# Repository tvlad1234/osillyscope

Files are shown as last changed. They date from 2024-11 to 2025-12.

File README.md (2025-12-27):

# osillyscope
CH32V003 OLED screen oscilloscope

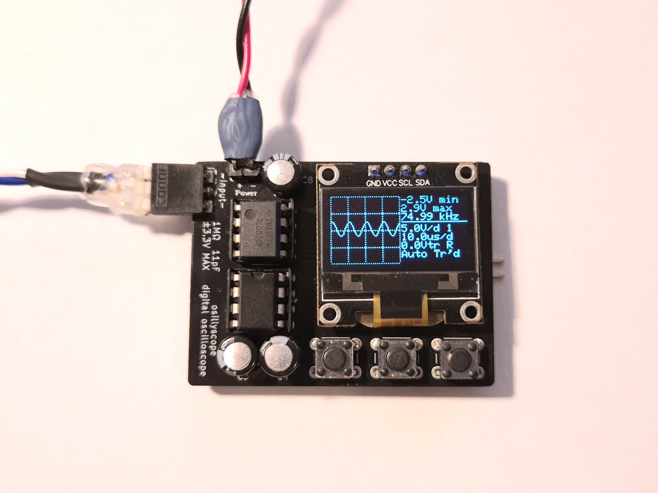
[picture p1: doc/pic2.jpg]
The osillyscope


 **Many thanks to [PCBway](https://www.pcbway.com/) for sponsoring this project with fast high-quality PCB prototyping.**

This is a small digital oscilloscope based around the CH32V003A4M6 RISC-V microcontroller. It uses an SSD1306 I2C OLED display and three pushbuttons for the user interface. Its purpose is to be an inexpensive, easy to build and pocket-sized tool for checking the presence, levels and waveform of an unknown signal. The hardware design focuses on simplicity and low-count bill of materials.

The maximum achievable sample rate is 1.6MSa/s (the time base goes as low as 5us/div). This project proposes a frontend design which allows for a signal input range between -3.3V and +3.3V. The input range can be extended using a standard 10x probe, as the instrument has 1MOhm of input impedance. The bandwidth of the frontend was measured to be around 2.5MHz. 

## Hardware
The schematics and board design files (KiCad 7) are provided in the [hw](hw) folder. Two PCB designs are included: [a 2-layer design, meant to be sent to a PCB fab](hw/osillyscope-2layer/) and [a single layer one, designed to be easily etchable](hw/osillyscope-etchable/).

### **PCBs**
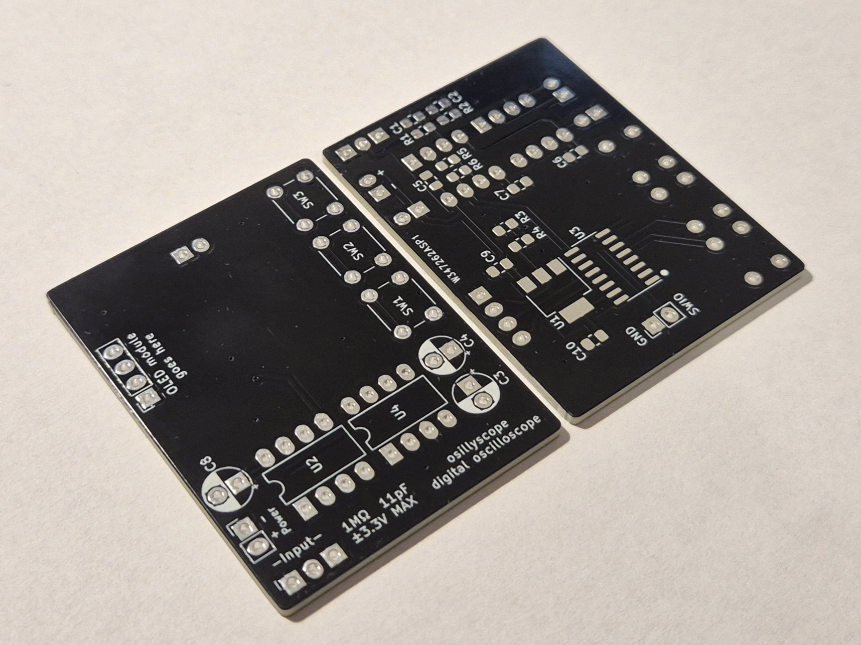
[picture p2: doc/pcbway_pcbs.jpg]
PCBs from PCBway


Very shortly after I had published this project, PCBWay reached out to me, offering to try their PCB prototyping services. About a week after placing the order, the boards had arrived, and here are my thoughts on the service they provided:

I'm very pleased with them. They feel dense and solid, I had absolutely no trouble soldering them up. With such a relatively simple, untested board design, I chose to go with HASL finish. While assembling, I had to desolder and resolder the power pin header, and the pads didn't show any signs of possible failure or fatigue (I had that happen often with various circuit boards in the past, but I had no issues with these ones). Visually, I opted for black solder mask. It looks absolutely beautiful, glossy and uniformly coated, honestly the picture above doesn't show it in all of its beauty. The silkscreen is crisp, precise and nicely aligned.

Ordering from them was quite a breeze using their KiCad plugin, which automatically plots and uploads the Gerber files into their ordering platform with a single click. I find their service affordable, I ordered 10 boards (2 layers, 1.6mm with HASL finish) and the price for the boards came to be 5USD.

This was my first experience with PCBWay's prototyping service, and it's been a pleasant one. I will certainly consider them again for my next PCB prototyping needs, and I warmly encourage you too will give them a try.

### Circuitry  
The analog frontend consists of a 2x attenuator, opamp buffer stage and DC offset stage. An ICL7660 voltage converter IC provides the negative supply voltage for the TL082 dual opamp. The oscilloscope can be powered from a 5 or more volts supply, such as a 9V battery.

The schematics are also provided as PDF, in [doc/schematic.pdf](doc/schematic.pdf).

## Code
The firmware source code is provided in the [fw](fw) folder. It uses the [ch32fun](https://github.com/cnlohr/ch32fun/) framework.

The ADC operates in continuous conversion mode and samples are fetched into a circular buffer via DMA. Triggering is achieved using the analog watchdog feature of the ADC.

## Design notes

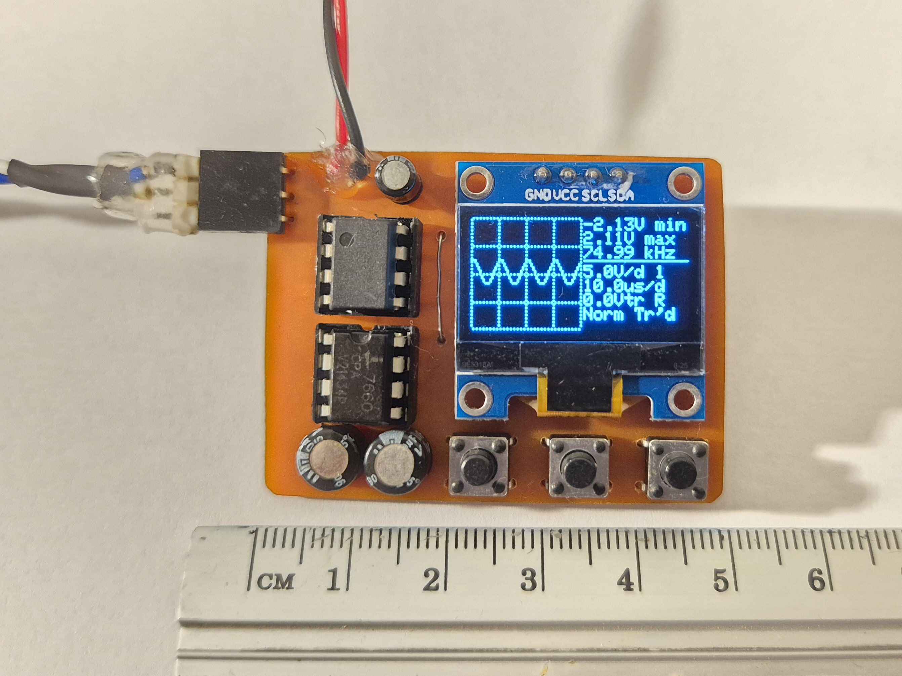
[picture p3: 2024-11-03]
doc/pic.jpg

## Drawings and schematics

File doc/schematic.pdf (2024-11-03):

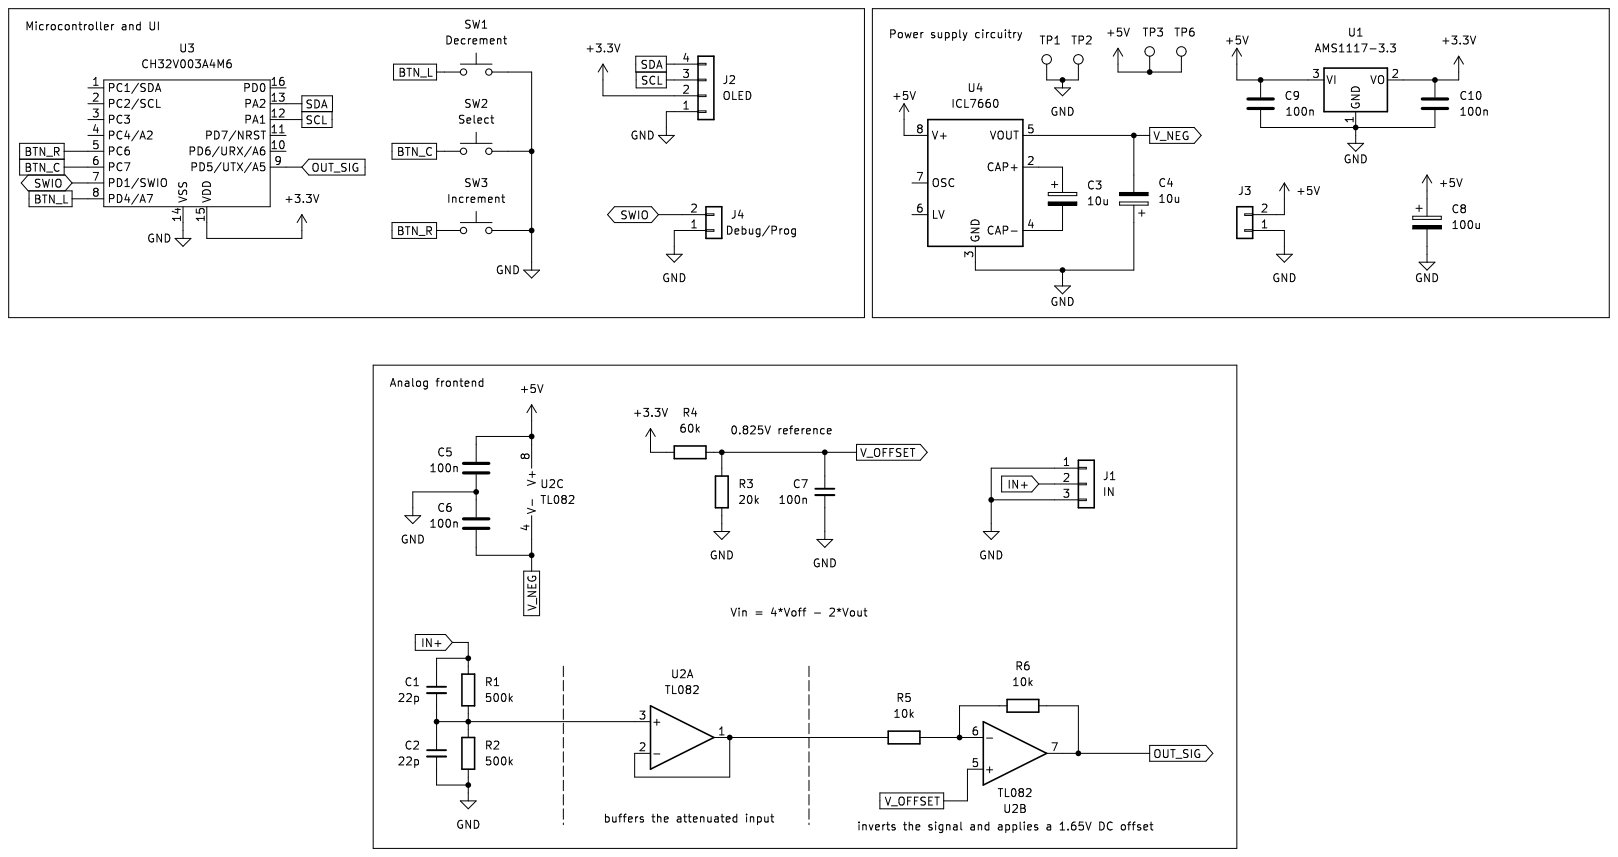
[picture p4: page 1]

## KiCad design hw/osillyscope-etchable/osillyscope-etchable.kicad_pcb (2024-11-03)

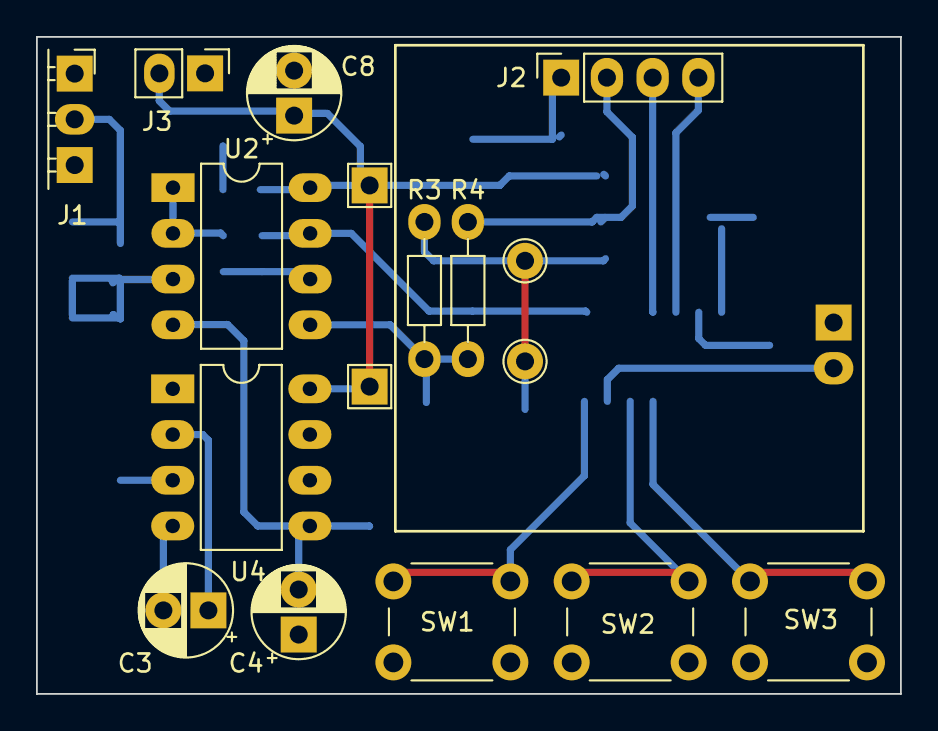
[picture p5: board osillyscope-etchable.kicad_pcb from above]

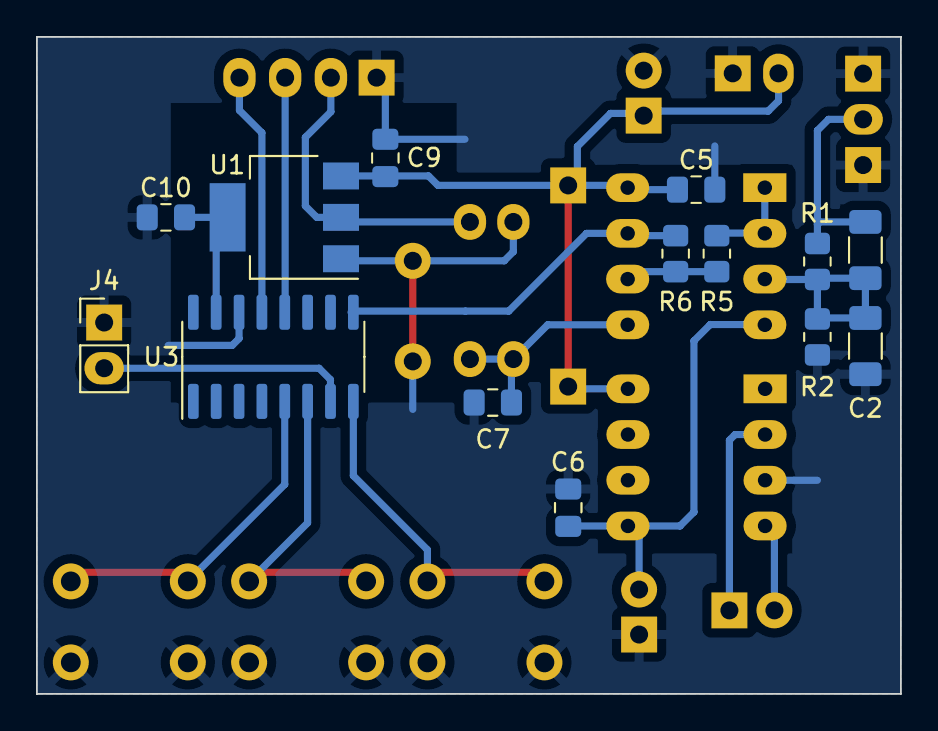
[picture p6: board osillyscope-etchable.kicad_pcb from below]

Board: 2 copper layers, 48.0 x 36.5 mm, 31 parts (14 on the bottom side), 18 nets.

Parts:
C1, C2: 22p; C_1206_3216Metric_Pad1.33x1.80mm_HandSolder
C3, C4: 10u; CP_Radial_D5.0mm_P2.50mm
C5, C6, C7, C9, C10: 100n; C_0805_2012Metric_Pad1.18x1.45mm_HandSolder
C8: 100u; CP_Radial_D5.0mm_P2.50mm
J1: IN; PinSocket_1x03_P2.54mm_Horizontal
J2: OLED; PinSocket_1x04_P2.54mm_Vertical
J3: Conn_01x02; PinHeader_1x02_P2.54mm_Vertical
J4: Debug/Prog; PinHeader_1x02_P2.54mm_Vertical
R1, R2: 500k; R_0805_2012Metric_Pad1.20x1.40mm_HandSolder
R3: 20k; R_Axial_DIN0204_L3.6mm_D1.6mm_P7.62mm_Horizontal
R4: 60k; R_Axial_DIN0204_L3.6mm_D1.6mm_P7.62mm_Horizontal
R5, R6: 20k; R_0805_2012Metric_Pad1.20x1.40mm_HandSolder
SW1: Decrement; SW_PUSH_6mm
SW2: Select; SW_PUSH_6mm
SW3: Increment; SW_PUSH_6mm
TP1, TP2: TestPoint; TestPoint_THTPad_D2.0mm_Drill1.0mm
TP3, TP6: TestPoint; TestPoint_THTPad_2.0x2.0mm_Drill1.0mm
U1: AMS1117-3.3; SOT-223-3_TabPin2
U2: TL082; DIP-8_W7.62mm_LongPads
U3: CH32V003A4M6; SOIC-16_3.9x9.9mm_P1.27mm
U4: ICL7660; DIP-8_W7.62mm_LongPads

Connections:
+3.3V: C10.1, J2.2, R4.1, U1.2 (VO), U3.15 (VDD)
+5V: C5.1, C8.1, C9.2, J3.2, TP3.1, TP6.1, U1.3 (VI), U2.8 (V+), U4.8 (V+)
BTN_C: SW2.1, U3.6 (PC7)
BTN_L: SW1.1, U3.8 (PD4/A7)
BTN_R: SW3.1, U3.5 (PC6)
GND: C2.2, C4.1, C5.2, C6.1, C7.2, C8.2, C9.1, C10.2, J1.1, J1.3, J2.1, J3.1, J4.1, R2.2, R3.2, SW1.2, SW2.2, SW3.2, TP1.1, TP2.1, U1.1 (GND), U3.14 (VSS), U4.3 (GND)
IN+: C1.1, J1.2, R1.1
unnamed: C1.2, C2.1, R1.2, R2.1, U2.3 (+)
unnamed: R5.1, U2.1, U2.2 (-)
unnamed: R5.2, R6.2, U2.6 (-)
unnamed: C3.1, U4.2 (CAP+)
unnamed: C3.2, U4.4 (CAP-)
OUT_SIG: R6.1, U2.7, U3.9 (PD5/UTX/A5)
SCL: J2.3, U3.12 (PA1)
SDA: J2.4, U3.13 (PA2)
SWIO: J4.2, U3.7 (PD1/SWIO)
V_NEG: C4.2, C6.2, U2.4 (V-), U4.5 (VOUT)
V_OFFSET: C7.1, R3.1, R4.2, U2.5 (+)

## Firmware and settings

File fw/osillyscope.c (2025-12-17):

/*
 * CH32V003 oscilloscope
 * by tvlad1234
 */

#include "ch32fun.h"

#include "scope.h"
#include "ui.h"

// ADC capture buffers
volatile uint16_t wave_buf[DISP_BUF_LEN] = {0};
volatile uint16_t adc_buf[CIRC_BUF_LEN] = {0}; // circular

oscilloscope_t oscope = {
	.wave_buf = wave_buf,
	.adc_buf = adc_buf,

	.dma_ready = 1,

	.trig_level = 502,
	.trig_state = NO_TRIGGER,

	.tdiv_sel = 1,
	.vdiv_sel = 2,

	.runmode = RUN_AUTO,
};

int main()
{
	SystemInit();
	RCC->APB2PCENR |= RCC_APB2Periph_GPIOD | RCC_APB2Periph_GPIOC | RCC_APB2Periph_GPIOA;

	// Let power supplies settle before initializing ADC and OLED
	Delay_Ms(250);

	init_oscilloscope(&oscope);

	while (1)
	{
		// Waveform capture
		capture_waveform(&oscope);

		// User interface
		scope_ui(&oscope);
	}
}

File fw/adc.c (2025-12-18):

#include "ch32fun.h"

#include "scope.h"

// available ADC clock dividers
const uint8_t availableAdcDivs[] = {2, 2, 4, 6, 8, 12, 16, 24, 32, 64, 96, 128, 0};

static oscilloscope_t *osc;

// initializes ADC and DMA at startup
void init_adc(oscilloscope_t *oscope)
{
    osc = oscope;

    // Start DMA clock
    RCC->AHBPCENR |= RCC_AHBPeriph_DMA1;

    // Enable DMA IRQ
    NVIC_EnableIRQ(DMA1_Channel1_IRQn);

    // ADCCLK = 24 MHz => RCC_ADCPRE = 0: divide by 2
    RCC->CFGR0 &= ~(0x1F << 11);

    // Enable GPIOC and set C4 as analog input
    RCC->APB2PCENR |= RCC_APB2Periph_GPIOC;
    AN_IN_GPIO->CFGLR &= ~(0xf << (4 * AN_IN_PIN)); // CNF = 00: Analog, MODE = 00: Input

    // Enable the ADC1 peripheral clock
    RCC->APB2PCENR |= RCC_APB2Periph_ADC1;

    // Reset the ADC to init all regs
    RCC->APB2PRSTR |= RCC_APB2Periph_ADC1;
    RCC->APB2PRSTR &= ~RCC_APB2Periph_ADC1;

    // Set sequencer to channel 2 only
    ADC1->RSQR3 = AN_IN_CH;

    // Possible times: 0->3,1->9,2->15,3->30,4->43,5->57,6->73,7->241 cycles
    ADC1->SAMPTR2 = 1 /*9 cycles*/ << (3 /*offset per channel*/ * AN_IN_CH /*channel*/);

    // turn on ADC
    ADC1->CTLR2 |= ADC_ADON;

    // Reset calibration
    ADC1->CTLR2 |= ADC_RSTCAL;
    while (ADC1->CTLR2 & ADC_RSTCAL)
        ;

    // Calibrate
    ADC1->CTLR2 |= ADC_CAL;
    while (ADC1->CTLR2 & ADC_CAL)
        ;

    // enable analog watchdog for single regular channel
    ADC1->CTLR1 |= ADC_AWDSGL;

    // set analog watchdog channel
    ADC1->CTLR1 |= AN_IN_CH;

    // Enable continuous conversion and DMA
    ADC1->CTLR2 |= ADC_CONT | ADC_DMA | ADC_EXTSEL;

    // clear analog watchdog flag
    ADC1->STATR = ~ADC_FLAG_AWD;

    // enable ADC interrupt
    NVIC_EnableIRQ(ADC_IRQn);

    // start conversion
    ADC1->CTLR2 |= ADC_SWSTART;

    adc_set_div(availableAdcDivs[osc->tdiv_sel]);
}

// Set the ADC clock divider
void adc_set_div(uint8_t div)
{
    osc->samp_per = 20.0f * (1 / 48.0f) * div;

    // hack to zoom in onto the waveform at the fastest sample rate (extend time base down to 5us/d)
    if (osc->tdiv_sel == 0)
        osc->samp_per = osc->samp_per / 2;

    RCC->CFGR0 &= ~((uint32_t)(0b11111) << 11);
    switch (div)
    {
    case 2:
        break;
    case 4:
        RCC->CFGR0 |= RCC_ADCPRE_DIV4;
        break;
    case 6:
        RCC->CFGR0 |= RCC_ADCPRE_DIV6;
        break;
    case 8:
        RCC->CFGR0 |= RCC_ADCPRE_DIV8;
        break;
    case 12:
        RCC->CFGR0 |= 0xA000;
        break;
    case 16:
        RCC->CFGR0 |= 0xE000;
        break;
    case 24:
        RCC->CFGR0 |= 0xA800;
        break;
    case 32:
        RCC->CFGR0 |= 0xE800;
        break;
    case 64:
        RCC->CFGR0 |= 0xF000;
        break;
    case 96:
        RCC->CFGR0 |= 0xB800;
        break;
    case 128:
        RCC->CFGR0 |= 0xF800;
        break;
    default:
        break;
    }
}

enum
{
    TRIG_AWDG_IDLE = 0,
    TRIG_AWDG_ARMED,
    TRIG_AWDG_HALF
};

volatile uint8_t trig_sm;

void adc_arm_trigger()
{
    if (osc->trig_slope == TRIG_FALLING)
    {
        // falling edge: arm when we're below the trigger level (outside of the set window)
        ADC1->WDLTR = osc->trig_level;
        ADC1->WDHTR = 1023;
    }
    else
    {
        // rising edge: arm when we're above the trigger level (outside of the set window)
        ADC1->WDLTR = 0;
        ADC1->WDHTR = osc->trig_level;
    }

    trig_sm = TRIG_AWDG_ARMED;
    osc->awdg_trigged = 0;                // clear trigger flag
    ADC1->STATR = ~ADC_FLAG_AWD;          // clear analog watchdog flag
    ADC1->CTLR1 |= ADC_AWDEN | ADC_AWDIE; // enable watchdog again, for next capture
}

void adc_update_trigger()
{
    if (trig_sm != TRIG_AWDG_IDLE) // if trigger is already armed
    {
        // stop
        ADC1->CTLR1 &= ~(ADC_AWDIE | ADC_AWDEN); // disable the watchdog and watchdog interrupt
        ADC1->STATR &= ~ADC_FLAG_AWD;            // clear the watchdog flag
        osc->awdg_trigged = 0;
        trig_sm = TRIG_AWDG_IDLE;

        // and re-arm
        adc_arm_trigger();
    }
}

// Interrupt handler for the ADC analog watchdog, used for triggering
void ADC1_IRQHandler(void) __attribute__((interrupt));
void ADC1_IRQHandler()
{
    if (ADC1->STATR & ADC_FLAG_AWD)
    {
        if (osc->dma_halves_filled >= 2)
        {
            if (trig_sm == TRIG_AWDG_ARMED)
            {
                trig_sm = TRIG_AWDG_HALF;

                if (osc->trig_slope == TRIG_FALLING)
                {
                    ADC1->WDLTR = 0;
                    ADC1->WDHTR = osc->trig_level;
                }
                else
                {
                    ADC1->WDLTR = osc->trig_level;
                    ADC1->WDHTR = 1023;
                }
            }
            else if (trig_sm == TRIG_AWDG_HALF)
            {
                // TRIGGER EVENT!
                // disable the watchdog and watchdog interrupt
                ADC1->CTLR1 &= ~(ADC_AWDIE | ADC_AWDEN);
                osc->awdg_trigged = 1;
                trig_sm = TRIG_AWDG_IDLE;
            }
        }
        ADC1->STATR &= ~ADC_FLAG_AWD; // clear the watchdog flag
    }
}

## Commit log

2024-11-03 refactor, change frontend voltage transf func, add sch and pcb
    [osillyscope.kicad_pcb, osillyscope.kicad_sch]
2024-11-03 Add image and pdf schematics, rephrase readme
2024-11-24 add 2layer board design, pcbway review
    [osillyscope-2layer.kicad_pcb, osillyscope-2layer.kicad_sch, osillyscope-etchable.kicad_pcb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]
2025-12-17 fix ADC interrupt flag and control bit clearing
    [scope.c]
2025-12-17 use circular buffer to capture pretrigger samples, not ready for production yet
2025-12-17 massive refactor to avoid using exported globals
    [adc.c, osillyscope.c, scope.c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]
2025-12-18 re-arm trigger on trigger point adjustment
